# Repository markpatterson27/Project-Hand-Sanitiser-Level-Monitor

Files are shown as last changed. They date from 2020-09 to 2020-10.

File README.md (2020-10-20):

# Project: Hand Sanitiser Level Monitor




IoT project looking at possible ways to measure the level of hand sanitiser left at sanitiser stations.

dataflow diagram

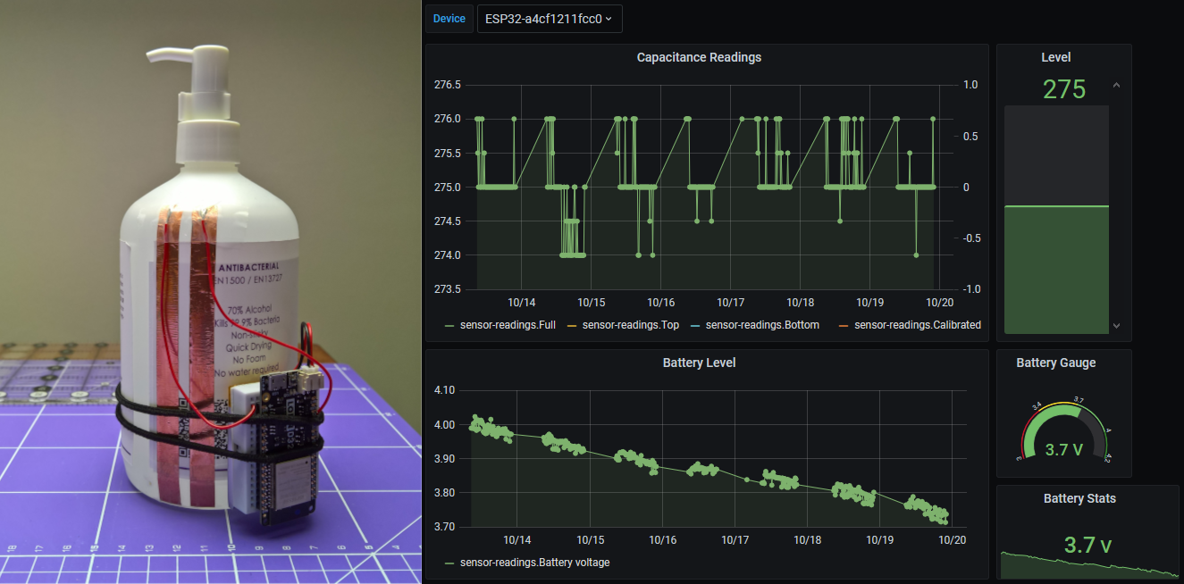
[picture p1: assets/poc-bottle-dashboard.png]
proof of concept bottle and dashboard


<br>

## Files and Folders

| File/Folder | Description |
|--- | --- |
| docker-compose-stack/ | Docker compose project |
| micropython/ | sync folder for micropython devices |
| micropython/cap_reading.py | micropython script that regularly reads capacitance and battery level and sends the data to a mqtt server. |
| micropython/level-test.py | micropython script that reads capacitance levels and displays a bar graph on a terminal screen. |
| mp-tests/ | folder for test files testing micropython project |
| powerbi-dasboards/ | some simple Power BI dashboards graphing data from the SQL Server container |
|  |  |

<br>

## Branches

**master**: main branch.  

<br>

## Configuration

### MQTT Topics

| MQTT Topic | Description |
| --- | --- |
| hand-sanitiser-levels/ | base topic for project |
| hand-sanitiser-levels/messages | topic for status messages |
| hand-sanitiser-levels/{client-id}/sensor-reading | sensor readings published on this topic as json |
| hand-sanitiser-levels/{client-id}/messages | topic for sending messages to devices |
| hand-sanitiser-levels/{client-id}/messages/led | topic to control on device led. payload should be a string and one of `on`, `off`, or `blink`. |
| hand-sanitiser-levels/{client-id}/messages/location | set the devices location. payload should be a string. |
| hand-sanitiser-levels/{client-id}/messages/poll-interval | topic to set poll interval on device. payload should be an integer. |
| hand-sanitiser-levels/{client-id}/messages/polling-hours | topic to set polling hours on device. payload should be json with following keys: `{'start': start hour, 'end': ending hour}`. hours should be integers. |
|  |  |

### Ports

Some of the docker services are mapped to non-standard ports.

| Port | Service |
|---|---|
| 123 | NTP |
| 1433 | SQL Server |
| 1883 | MQTT Broker |
| 3000 | Grafana |

<br>

### Database

| Database | HandSanitiserLevels |
|---|---|
| Tables/Measures | sensor-readings |
| Retention Policies: | 2_weeks (default) |
|  | 4_years |
| Continuous Queries: | cq_1h - `mean(*) INTO 4_years FROM 2_weeks GROUP BY time(60m), *` |

<br>

## Circuit Diagram - Single Wire
Wire the components as shown in the diagram. Place the other end of the wire on the liquid volume to be measured.

<!-- ![circuit diagram](assets/###-circuit-diagram_schem.svg) -->

#### Components Needed
* wire
* ESP32 dev board (Lolin D32)

<br />

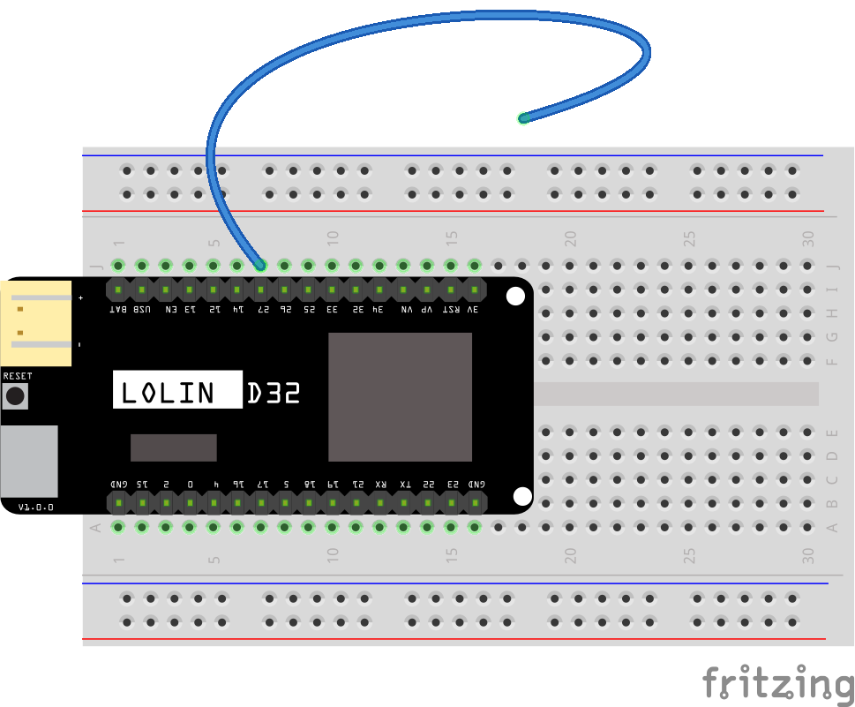
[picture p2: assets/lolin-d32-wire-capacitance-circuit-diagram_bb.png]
breadboard diagram


<br />

### Default Pin Wiring

| Pin No | Function | Device Connection |
| --- | --- | --- |
| 27 | GPIO27/Touch7 | Wire strand |
|  |  |  |

<br />

## Circuit Diagram - Multi-Point Foil Strips
Wire the components as shown in the diagram. Place the other end of the wire on the liquid volume to be measured.

<!-- ![circuit diagram](assets/###-circuit-diagram_schem.svg) -->

#### Components Needed
* wire
* foil tape
* ESP32 dev board (Lolin D32)

<br />

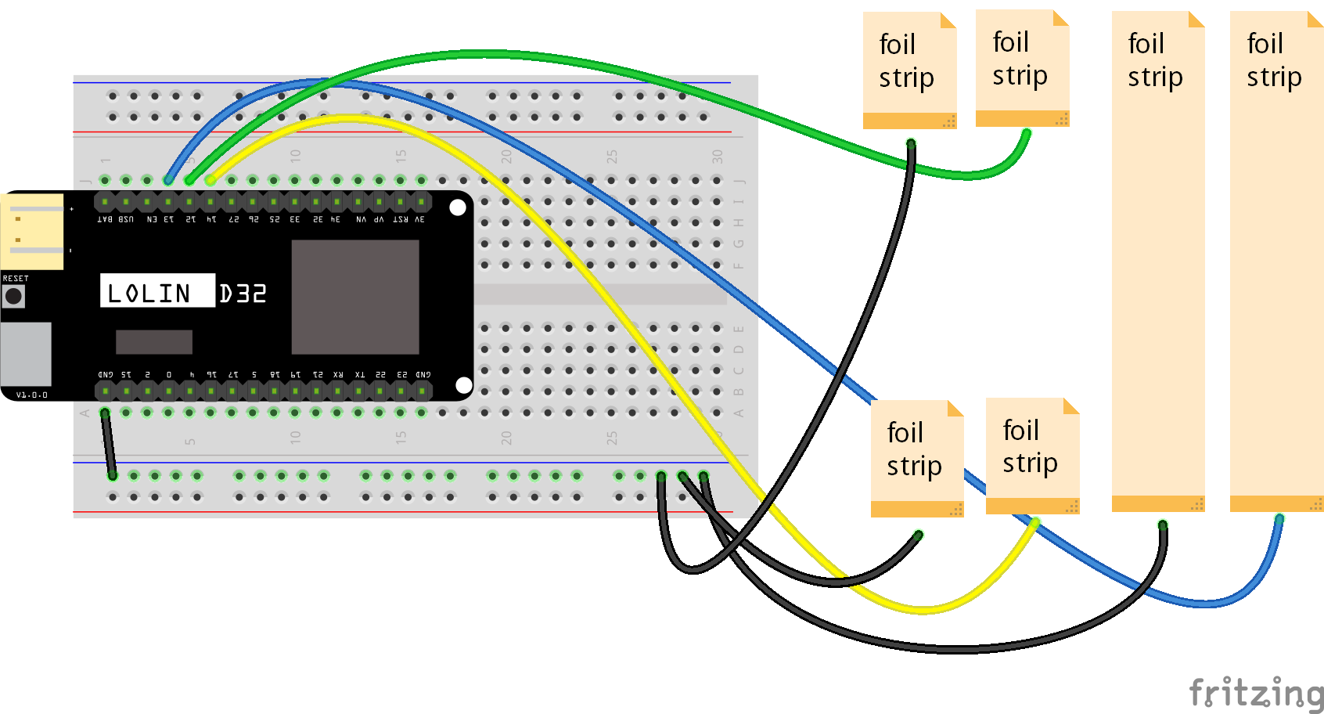
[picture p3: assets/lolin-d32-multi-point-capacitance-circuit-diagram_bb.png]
breadboard diagram


<br />

### Default Pin Wiring

| Pin No | Function | Device Connection |
| --- | --- | --- |
| 13 | GPIO13/Touch4 | Full height strip |
| 12 | GPIO12/Touch5 | Top strip |
| 14 | GPIO14/Touch6 | Bottom strip |
|  |  |  |

<br />

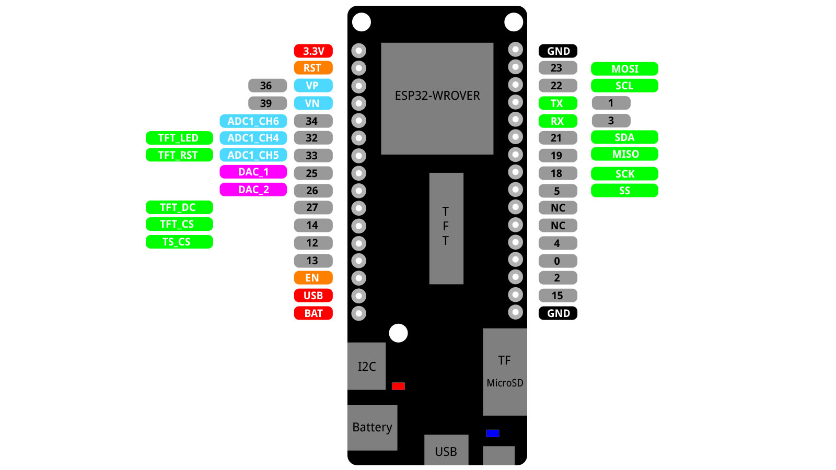
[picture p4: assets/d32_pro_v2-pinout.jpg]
pin diagram


<br />

## Level Test

This test was performed to determine if there was enough change in capacitance between full and empty to be able to reliably determine the level of sanitiser in the container. The script [level_test.py](micropython/level_test.py) was used. This script measures capacitance on a foil script, self-calibrating maximum and minimum readings, then calculates a percentage level for the current reading. This level is displayed on the serial connection as a bar graph.

level test gif

<br />

## References

- Testing stubs: https://github.com/tflander/esp32-machine-emulator

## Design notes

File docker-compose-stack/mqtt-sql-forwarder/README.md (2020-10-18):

# Docker MQTT-SQL Forwarder

Docker container with python script that forwards MQTT messages into an SQL database.

The forwarder script subsribes to all messages on a given base topic. The forwarder then filters and processes received messages, before writing data points to an SQL database.

<br />

## MQTT Message Structure

Received MQTT messages are expected to be structured as follows. The forwarder script will need to be modified if different structured messages are needed.

### MQTT Topics

All messages on the base topic are subscribed to: i.e. `BASE_TOPIC+'/#'`. The following sub-topics are processed. All other sub-topics are ignored.

| Topic | Description |
| --- | --- |
| last child topic: `/sensor-reading` | Any message with the last child topic of `sensor-reading`. |
|  |  |

<br />

### MQTT Payload

The MQTT payload is expected to be in the format:

```js
payload {
    "timestamp": "<timestamp of reading>",
    "meta-data": {
        // this is data that doesn't need to be graphed or processed,
        // but could be used for filtering
        // this data is likely to be strings and unlikely to be numerical
        "<dictionary of meta-data associated with sensor reading>"
    },
    "measures": {
        // this is data that will be processed and/or graphed
        // this data will be numerical
        "<dictionary of sensor readings>"
    }
}
```

## SQL Data Rows

Sensor values are written into a `SensorReadings` table. MQTT message payloads have to be specifically mapped to SQL columns.

**Table structure:**  
| Column | Description |
| --- | --- |
| Id | Auto-generated Id number. Primary key|
| Datestamp | Date and time of reading |
| Device | Id of device taking reading |
| Location | Location of device |
| Method | Method used to gather sensor readings |
| CapacitanceFullLength | Capacitance value of full length foil strips |
| CapacitanceTop | Capacitance value of short foil strips  at top of measurement level |
| CapacitanceBottom | Capacitance value of short foil strips  at bottom of measurement level |
| CapacitanceCallibrated | Value generated from full length reading divided by difference between top and bottom readings |
| BatteryLevel | Voltage level reading of battery |

<br />

**Example data:**  
| Id | Datestamp | Device | Location | Method | CapacitanceFullLength | CapacitanceTop | CapacitanceBottom | CapacitanceCallibrated | BatteryLevel |
| --- | --- | --- | --- | --- | --- | --- | --- | --- | --- |
| 1 | 2020-10-17 10:00:00 | ESP32-abc | somewhere | multipoint | 450 | 400 | 460 | 7.5 | 3.9 |
| 2 | 2020-10-17 10:01:00 | ESP32-xyz | somewhere | single | 250 |  |  |  | 3.7 |

<br />

## References

- https://pypi.org/project/paho-mqtt/
- https://github.com/mkleehammer/pyodbc
- https://github.com/vbentley/docker-base-images
- https://docs.microsoft.com/en-us/sql/connect/odbc/linux-mac/installing-the-microsoft-odbc-driver-for-sql-server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

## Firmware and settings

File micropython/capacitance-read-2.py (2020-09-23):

import machine
import time

charge_pin = machine.Pin(15, machine.Pin.OUT)
read_pin = machine.Pin(13, machine.Pin.IN)

while True:
    charge_pin.on()
    time.sleep(2)
    
    count = 0
    
    charge_pin.off()
    while read_pin.value():
       count = count + 1
        
    print("      ", end='\r')
    print(count, end='\r')
    # print(read_pin.value())
    

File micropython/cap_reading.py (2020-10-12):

# program flow
#  - connect to wifi
#  - check if clock set; if not set clock
#  - read capacitances
#  - read battery level
#  - send mqtt message
#  - blink led sucessful/not successful
#  - device sleep

import machine
import utime
import network
import ntptime
import uos
import ubinascii
from umqtt.simple import MQTTClient
import json
import d32_batterymon
import d32_led

import config

# check if const() defined
try:
    x = const(1)
except NameError:
    print("const not defined")
    const = lambda x: x

# define sensor type
METHOD = "multipoint"
# METHOD = "single"

# define pins
FULL_PIN = const(13)
TOP_PIN = const(12)
BOTTOM_PIN = const(14)
LED_PIN = config.LED

# setup inputs and outpus
t_full = machine.TouchPad(machine.Pin(FULL_PIN))
t_top = machine.TouchPad(machine.Pin(TOP_PIN))
t_bottom = machine.TouchPad(machine.Pin(BOTTOM_PIN))
led = machine.Pin(LED_PIN, machine.Pin.OUT, value=1)

# MQTT settings
SERVERS = config.MQTT_SERVERS
CLIENT_ID = uos.uname()[0].upper().encode('utf-8') + b"-" + ubinascii.hexlify(machine.unique_id())
BASE_TOPIC = b"hand-sanitiser-levels"
SUBSCRIBE_TOPIC = BASE_TOPIC + b'/' + CLIENT_ID + b'/messages/#'

settings = {
    'led_status_blink': True,
    'poll_interval': 5,   # time in minutes
    'polling_hours' : {    # hour of day
        'start': 8,
        'end': 20
    },
    'location': "nowhere"
}

led_blink = False
led_blink_count = 10

# NTP settings
# ntptime.host = config.NTP_SERVER


# try connecting to access point
def try_connection(nic):
    t = 12
    # console_queue.append(['trying to connect to {}'.format(nic), 10])
    while not nic.isconnected() and t > 0:
        print('.', end='')
        utime.sleep_ms(500)
        t = t - 1
    return nic.isconnected()

# connect to WiFi
def wifi_connect():
    wlan = network.WLAN(network.STA_IF)
    wlan.active(True)

    print('connecting to last AP', end='')
    print(try_connection(wlan))
    utime.sleep(2)
    if not wlan.isconnected():
        ## find all APs
        ap_list = wlan.scan()
        ## sort APs by signal strength
        ap_list.sort(key=lambda ap: ap[3], reverse=True)
        ## filter only trusted APs
        ap_list = list(filter(lambda ap: ap[0].decode('UTF-8') in 
                config.ACCESS_POINTS.keys(), ap_list))
        for ap in ap_list:
            if not wlan.isconnected():
                essid = ap[0].decode('UTF-8')
                print('connecting to new AP:', essid, end='')
                wlan.connect(essid, config.ACCESS_POINTS[essid])
                print(try_connection(wlan))
                utime.sleep(2)
            elif wlan.isconnected():
                break
    print('network config: {}'.format(wlan.ifconfig()))

# set rtc
def set_time():
    time_set = False
    for _ in range(2):
        try:
            ntptime.settime()
        except:
            print('ntp timeout')
        else:
            time_set = True
            break
    if not time_set:
        ntptime.host = config.NTP_SERVER
        try:
            ntptime.settime()
        except:
            print('ntp timeout')

# mqtt callback
def mqtt_cb(topic, msg):
    global led_blink, led_blink_count
    global settings

    print("message received")
    print("topic: ", topic)
    print("message: ", msg)

    # led control
    if topic == SUBSCRIBE_TOPIC[:-1]+ b"led":
        if msg == b"on":
            settings['led_status_blink'] = True
        elif msg == b"off":
            settings['led_status_blink'] = False
        elif msg.split(b":")[0] == b"blink":
            led_blink = True
            try:
                if msg.split(b":")[1].isdigit() and int(msg.split(b":")[1]) != 0:
                    led_blink_count = int(msg.split(b":")[1])
                else:
                    led_blink_count = 10
            except IndexError:
                led_blink_count = 10

    # set location
    elif topic == SUBSCRIBE_TOPIC[:-1]+b"location":
        settings['location'] = msg.decode()
        print("location: ", settings['location'])
    
    # change polling interval
    elif topic == SUBSCRIBE_TOPIC[:-1]+b"poll-interval":
        # if msg.isdigit():
        if isinstance(msg, int):
            settings['poll_interval'] = msg
        print("poll interval: ", settings['poll_interval'])

    # change polling hours
    elif topic == SUBSCRIBE_TOPIC[:-1]+b"polling-hours":
        m = json.loads(msg)
        # if msg[0]['start'].isdigit():
        if 'start' in m and isinstance(m['start'], int):
            settings['polling_hours']['start'] = m['start']
        # if msg[0]['end'].isdigit():
        if 'end' in m and isinstance(m['end'], int):
            settings['polling_hours']['end'] = m['end']
        print("polling hours: ", settings['polling_hours'])

    machine.RTC().memory(json.dumps(settings))    # save settings to rtc memory
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

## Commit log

2020-09-05 added circuit diagram
    [circuit-diagram.fzz, lolin-d32-wire-capacitance-circuit-diagram.fzz]
2020-09-05 added script for reading capacitance in loop
2020-09-23 added test script for esp8266 capacitance measuring
2020-09-23 added diagrams for multi-point capacitance measuring
    [lolin-d32-multi-point-capacitance-circuit-diagram.fzz]
2020-09-23 Added wiring notes for multi-point capacitance
2020-09-23 fix pin numbers
2020-09-25 added capacitance calibration calculation
2020-09-27 track docker .env file
2020-09-29 polling interval: calculate remaining minutes from current hour, not polling end hour
2020-09-30 fix split brackets
    fix error blink loop
    fix: don't int for isdigit
2020-09-30 added some print statements for debugging
2020-10-02 fix send sensor readings on sensor-reading topic
2020-10-07 added option for capacitiance reading method
2020-10-07 fix rtc memory access
    [cap_reading.py]
2020-10-12 added tests for led messages
2020-10-12 added reference for esp32-machine-emulator to README
2020-10-12 fix poll-interval and polling-hours message parsing
    [cap_reading.py]
2020-10-12 fix polling hours set parsing
    [cap_reading.py]
2020-10-18 changed message filtering in forwarder
2020-10-18 only process sensor readings if there are sensor readings
2020-10-18 fix calibrated typos
2020-10-20 added power bi files
